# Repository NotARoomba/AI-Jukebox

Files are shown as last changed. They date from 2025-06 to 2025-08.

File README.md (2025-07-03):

<h1 align="center"> 
  <br>
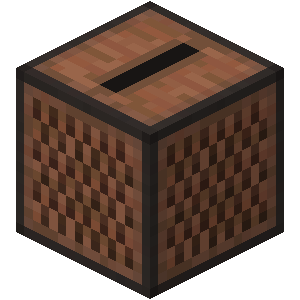
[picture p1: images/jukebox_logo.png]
Jukebox concept
  
  <br>
  AI Jukebox 
</h1>

<h4 align="center">A Minecraft‑inspired AI‑powered music jukebox using NFC‑tagged disks!

(Heavily) Inspired by [@danieliscrazy's jukebox](https://github.com/danieliscrazy/jukebox)

</h4>

<div align="center">





</div>

<p align="center">
  <a href="#key-features">Key Features</a> •
  <a href="#components-and-costs">Components & Costs</a> •
  <a href="#case-and-cad">Case & CAD</a> •
  <a href="3pcb-and-wiring">PCB & Wiring</a> •
  <a href="#credits">Credits</a>
</p>

## Key Features

- **NFC‑enabled Disks**: Insert‑to‑play AI‑generated tracks or playlists.
- **Satisfying Push‑Push Mechanics**: Disks can be entered and pushed out with a nice mechanism.
- **Custom Cube Frame**: 16 cm wooden case with 3D printed internals.
- **Audio Output**: Integrated speaker + MAX98357 amplifier, with Bluetooth support (via Raspberry PI).
- **Raspberry Pi Zero 2 W**: Powers logic and audio playback.
- **Playback Buttons**: Play/pause, fast forward/skip, or rewind/unskip music.

## Components & Costs

| Item | Price (COP) | Price (USD) | Source |
| --- | --- | --- | --- |
| Raspberry Pi Zero 2 W | 78,018 | 18.92 | [Aliexpress](https://es.aliexpress.com/item/1005007064834607.html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) |
| Speaker Amp Max98357  | 22,140 | 5.40 | [Online Marketplace](https://articulo.mercadolibre.com.co/MCO-2424374156-max98357-dac-convertidor-digital-analogico-amplificador-3w-_JM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) |
| Speaker | 23,024 | 5.67 | [Online Marketplace](https://www.mercadolibre.com.co/n-altavoz-tweeter-de-3-pulgadas-alta-fidelidad-4-ohmios/p/MCO2001722597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) |
| NFC Tags | 44,105 | 10.70 | [Online Marketplace](https://www.mercadolibre.com.co/a-100-unidadeslote-para-telefonos-con-chip-ntag215-nfc-pvc/p/MCO2011890227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) |
| RFID Kit RC522 | 12,500 | 3.03 | [Online Marketplace](https://articulo.mercadolibre.com.co/MCO-592398205-kit-rfid-rc522-receptor-tarjeta-y-llavero-_JM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) |
| Push Push Mechanism | 19,400 (already bought) | 4.71 | Local Hardware Store |
| 1cm Blocks of Wood | 33,760 (each, 2 units)  | 8.19 | [Temu](https://share.temu.com/08dAAkNGvvA) |
| Wood Glue | 19,900 | 4.83 | [Local Hardware Store](https://www.homecenter.com.co/homecenter-co/product/203373/pegante-carpincol-para-madera-250-gramos/203373/) |
| MX-Style Switches | 0 (already bought) | 0.00 | Already Purchased |
| DSA Keycaps | 0 (already bought) | 0.00 | Already Purchased |
| **SubTotal** | **307,650** | **74.68** | |
| **Shipping Costs** | **105,000** | **25.00** | Estimated |
| **Total** | **412,650** | **99.68** | |

## 📐 Case & CAD

- Designed in Fusion 360 as a 16 cm cube.
- 3D printed internal supports, wooden outer shell, and speaker cut‑out.
- Push‑push hardware custom‑fitted into disk slot.
- Buttons to play/pause, fastforward, and rewind

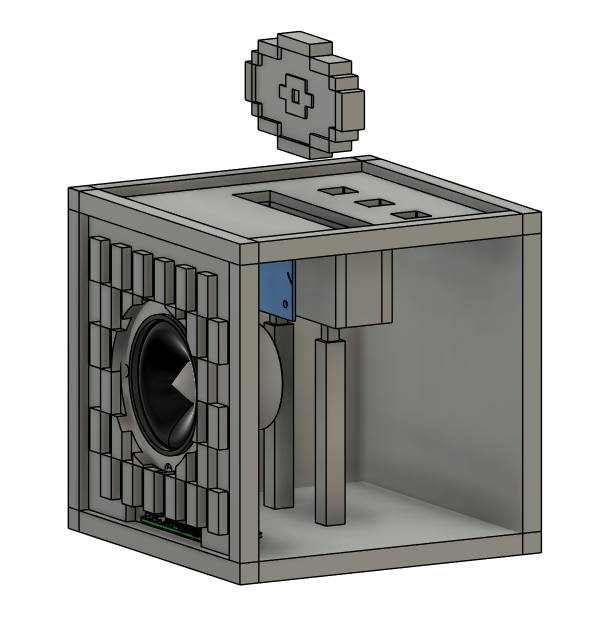
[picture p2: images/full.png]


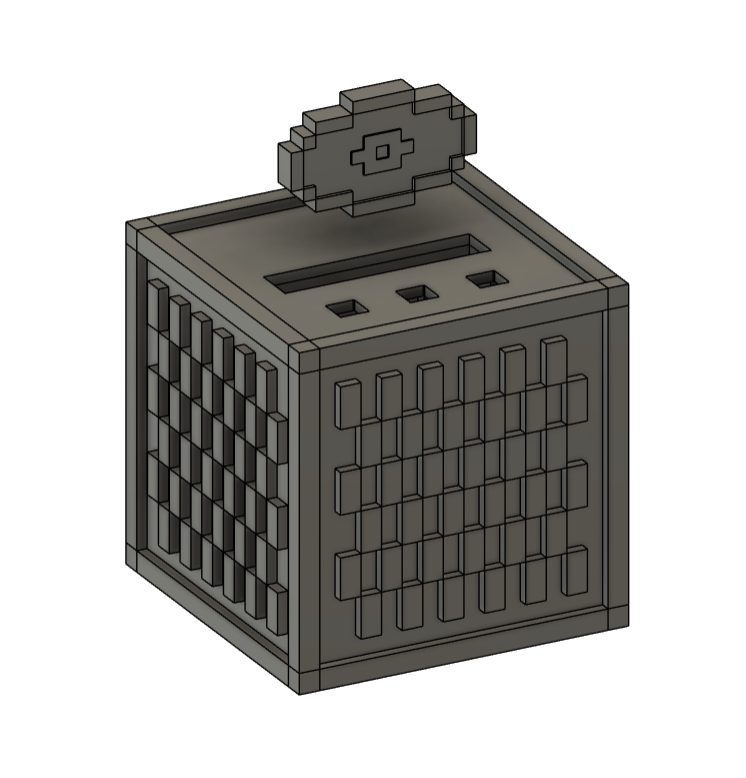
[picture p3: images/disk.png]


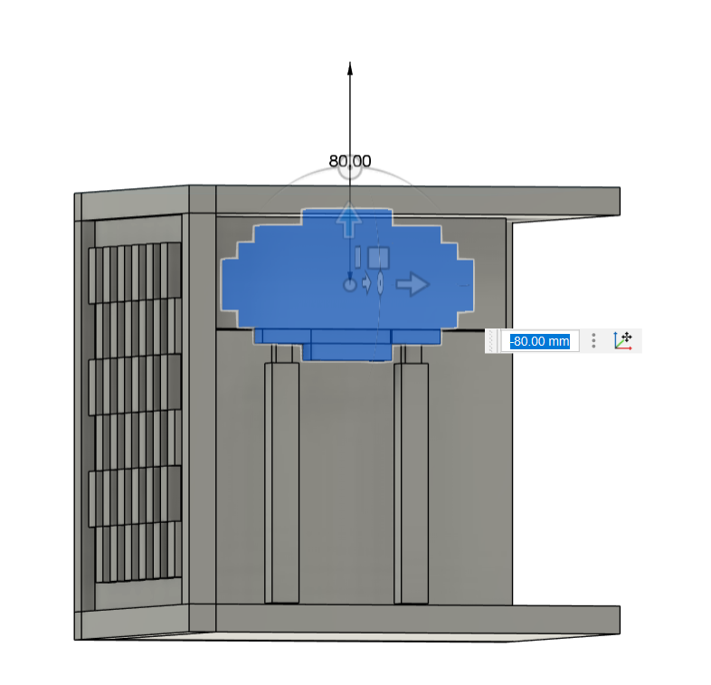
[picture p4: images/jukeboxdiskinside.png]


## PCB & Wiring

- Designed wiring in KiCad for Raspberry Pi ↔ RC522 NFC ↔ MAX98357 amp.
- Followed PiMyLifeUp tutorial for RC522, and Adafruit guide for MAX98357 wiring.
- MX-Style switches for play/pause and other functionality.

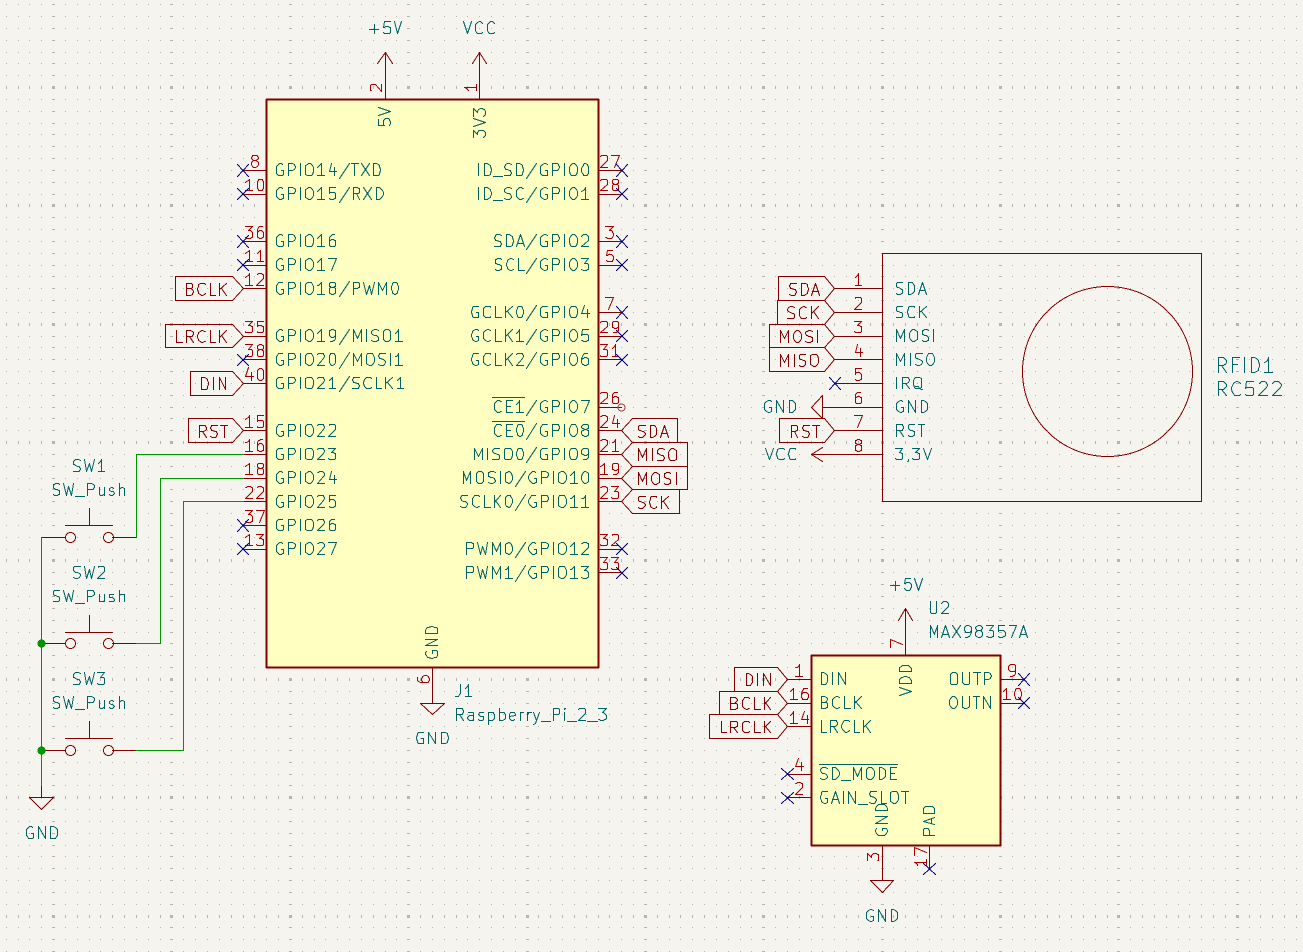
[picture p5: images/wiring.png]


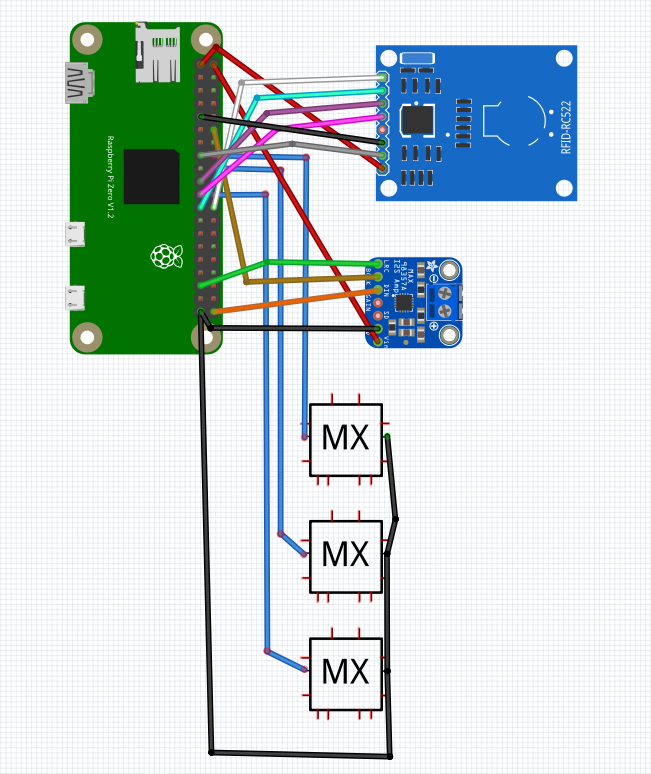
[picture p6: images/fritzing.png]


## Credits

Inspired by [@danieliscrazy's jukebox](https://github.com/danieliscrazy/jukebox)

This project uses:

- [KiCad](https://www.kicad.org/)
- [Python](https://www.python.org/)
- [Fusion 360](https://www.autodesk.com/products/fusion-360/overview)
- [RC522 Tutorial](https://pimylifeup.com/raspberry-pi-rfid-rc522/)
- [I2S Amp Guide](https://learn.adafruit.com/adafruit-max98357-i2s-class-d-mono-amp/raspberry-pi-wiring)

## You may also like...

- [Tamaki](https://github.com/NotARoomba/Tamaki) – Tamagotchi macropad
- [NivelesDeNiveles](https://github.com/NotARoomba/NivelesDeNiveles) – Flood alert app
- [ROCKETMEN](https://github.com/NotARoomba/ROCKETMEN) – Flight controller files

## License

MIT

> Disclaimer: Artificial intelligence was used in the making of this project's code and for some functionality. See `firmware/main.py` for more details.

---

> [notaroomba.dev](https://notaroomba.dev) &nbsp;&middot;&nbsp;
> GitHub [@NotARoomba](https://github.com/NotARoomba)

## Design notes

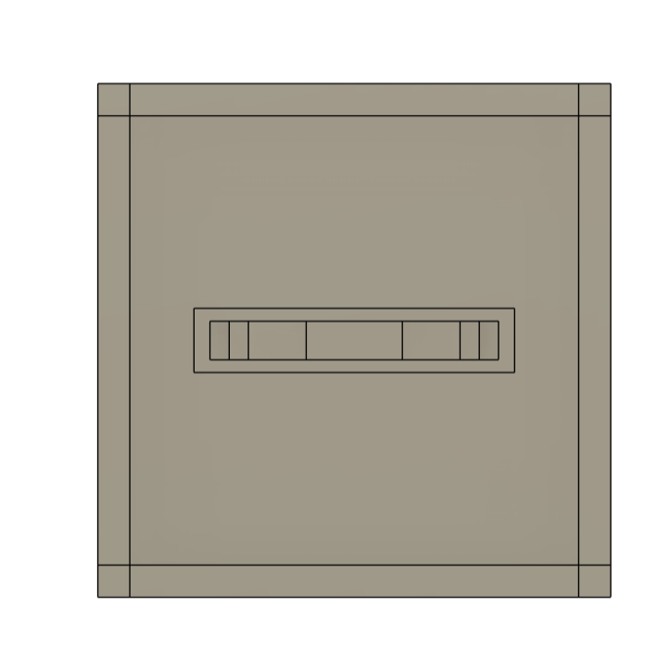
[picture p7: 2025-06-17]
images/disk_top.png

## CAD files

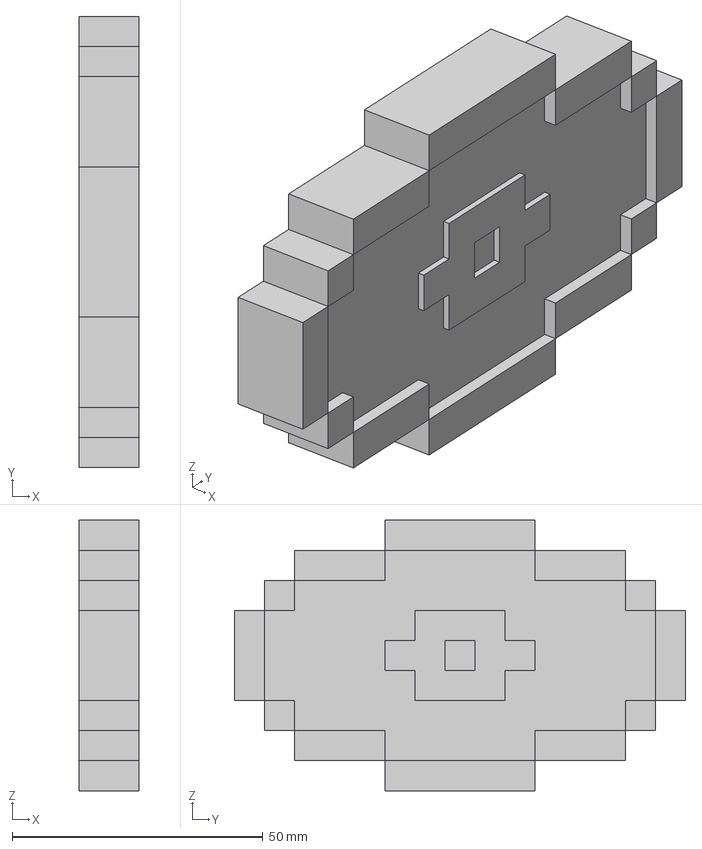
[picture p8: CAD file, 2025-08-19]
cad/Disk Hole.step
12.0 x 90.0 x 54.0 mm

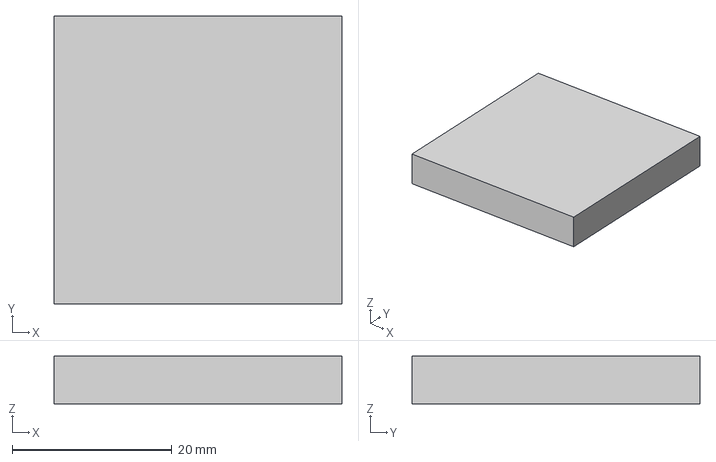
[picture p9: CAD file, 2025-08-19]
cad/Disk Test.step
36.0 x 36.0 x 6.00 mm

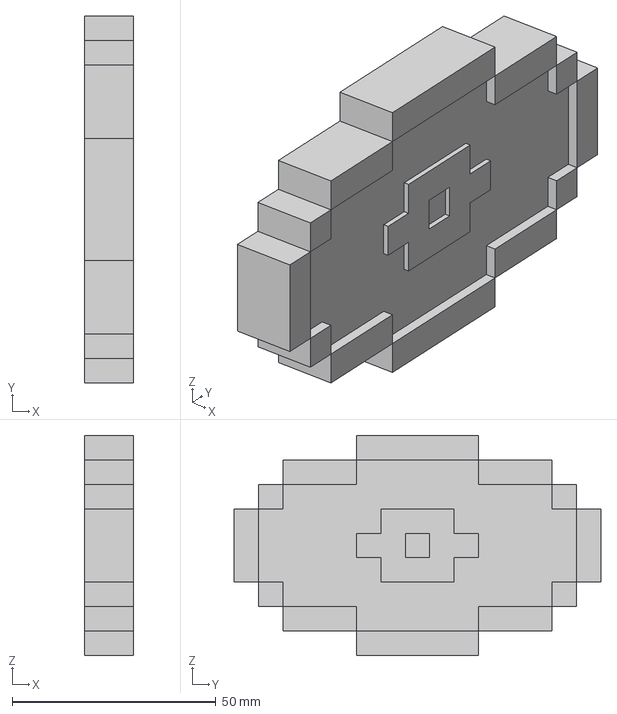
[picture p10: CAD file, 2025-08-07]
cad/Disk.step
12.0 x 90.0 x 54.0 mm

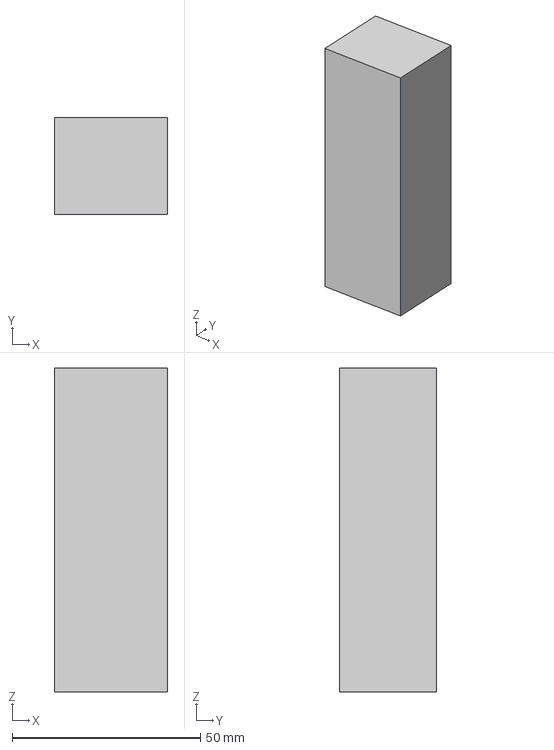
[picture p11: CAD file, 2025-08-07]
cad/Jukebox Support.step
30.0 x 25.7 x 86.0 mm

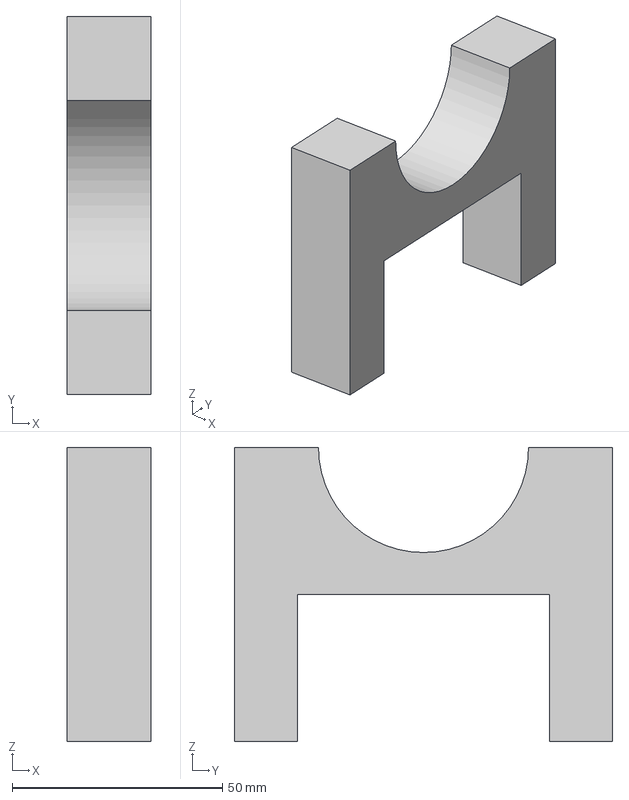
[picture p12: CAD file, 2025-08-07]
cad/Speaker Holder.step
20.0 x 90.0 x 70.0 mm

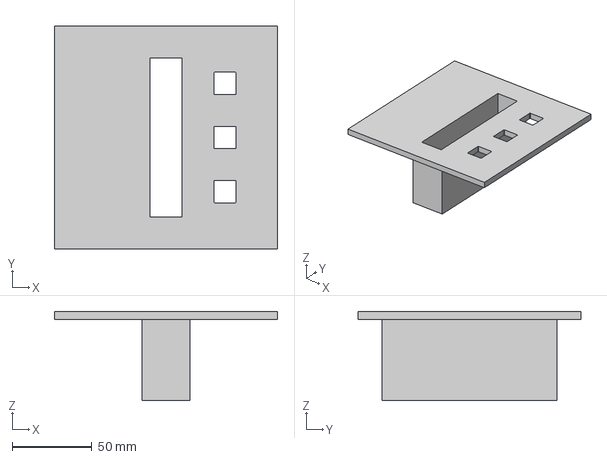
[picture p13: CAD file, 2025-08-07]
cad/Jukebox Top.step
140.0 x 140.0 x 56.0 mm

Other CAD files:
cad/Jukebox v21.f3z

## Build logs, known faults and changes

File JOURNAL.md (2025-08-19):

---
title: "AI Jukebox"
author: "Nathan Alspaugh (NotARoomba)"
description: "A Minecraft inspired jukebox that plays AI-generated music/albums from discs!"
created_at: "2025-06-13"
time_spent: ~23 Hours
---

# June 13: Brainstorming (~2 Hours)

I got inspired by the jukebox that was made and wanted to try and make my own with more features. One thing I had in mind was to have disks that have specific "prompts" encoded in the NFC tags to play music generated through Sumo from the prompt. Then I also wanted to have album-like disks where they play an album from spotify or something. Also a push-push mechanism for the disks as I think that feature would be satisfying to put in/take out the disks. I plan on making the frame from blocks of wood and then the insides with a combination of 3D printed parts. I would like to be able to place a speaker inside or for it to be able to connect to a speaker with aux/bluetooth.

# June 14: More Brainstorming and Case Design (~7 Hours)

I was looking into the different types of wood finishes as I wanted a jukebox that looked nice on the outside (the inside aswell) so I researched the wood types that I wanted to buy. For the border, I wanted an ebony or other dark wood, for the sides, I'm thinking about using a red mahogany/black walnut mix to create texture, and for the rest of the sides, maybe cherry wood.

I also worked on the case in Fusion360, it is going to be a cube thats 16x16x16cm.

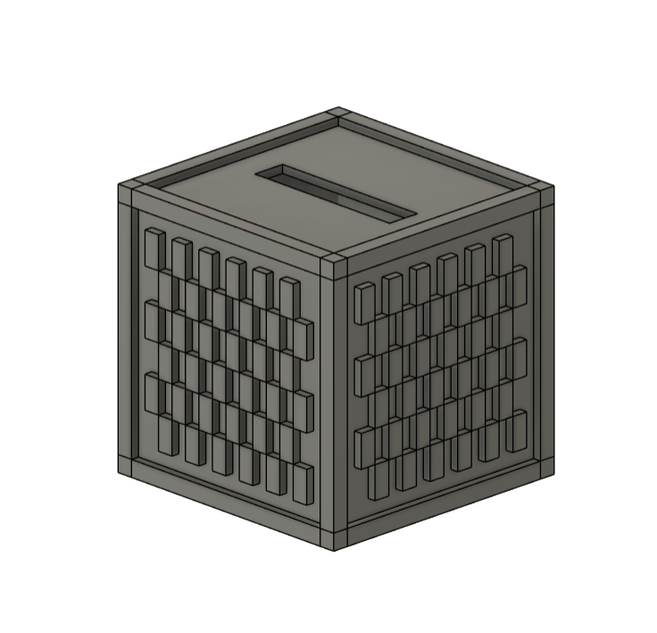
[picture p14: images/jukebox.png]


I also bought 2 "push push" cabinet mechanisms at my local hardware store to use for the disk. They are a bit strong so it will have enough force to literally "eject" the disk.



# June 15: Disc Design and Slot (~6 Hours)

I started design on the disk design and the slot in which the disks were going to be pushed into, keeping in mind the dimensions for the 2 push push mechanisms.

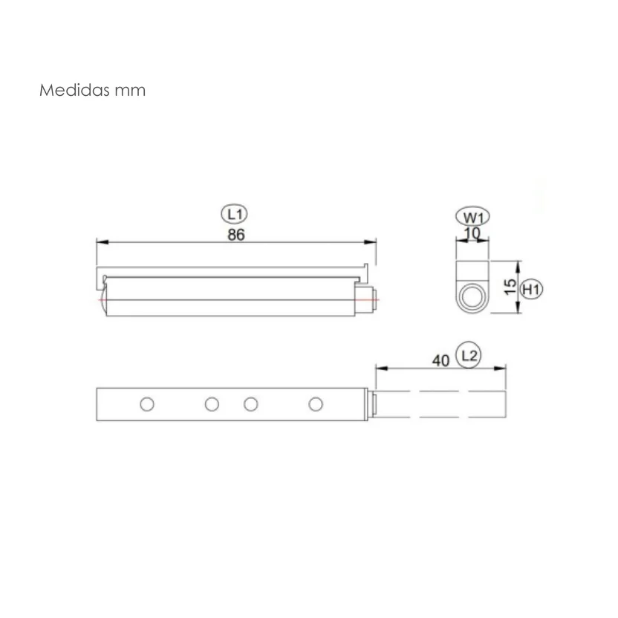
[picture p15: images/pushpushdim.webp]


I added in the 2 push mechanisms in to the bog to discover that they fit perfectly

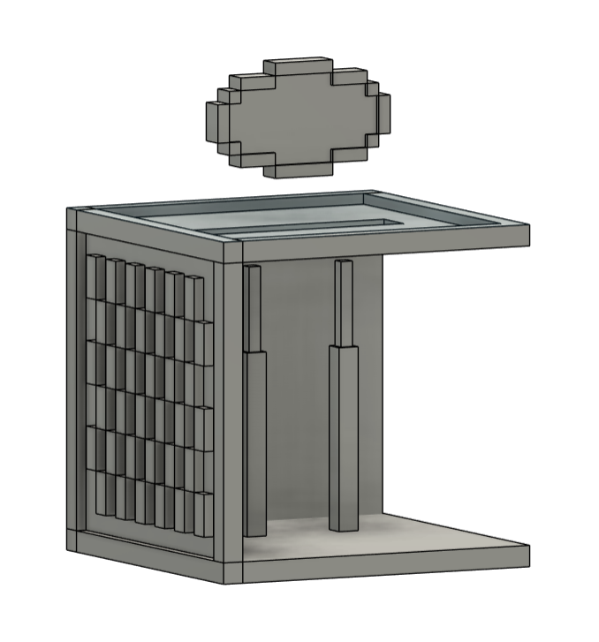
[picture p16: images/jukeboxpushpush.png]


Obviously there is going to be a "guide" for the disk so that it doesn't get jammed, I'll add the nfc tag reader to the side.



After that I added a hole for the speaker and the cables for the Raspberry Pi.

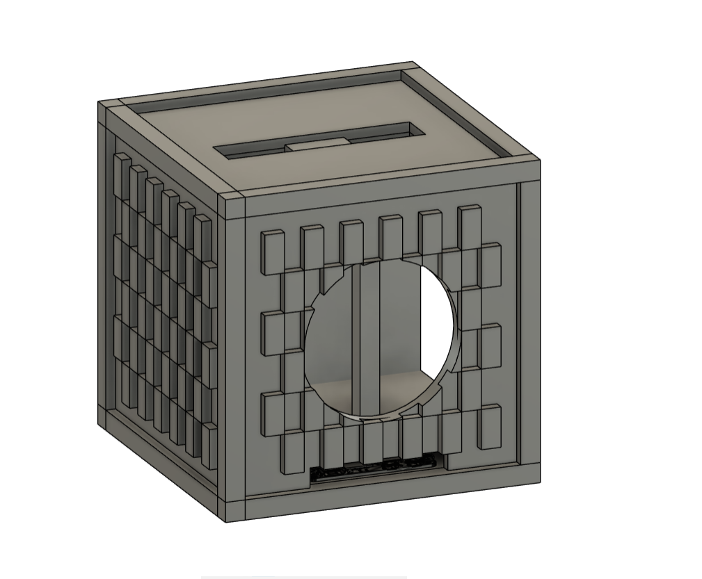
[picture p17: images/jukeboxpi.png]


# June 16: Connections (~6 Hours)

I went to the center of my city to try and find ebony but I had to leave because it is a semi dangerous place and I felt unsafe. I plan on returning with my mom to see if we can find it but for now I plan on ordering cubes on Temu and painting/staining them.

After making the box I fired up KiCad to connct the components, following a [tutorial](https://pimylifeup.com/raspberry-pi-rfid-rc522/) to connect the NFC reader to the Raspberry Pi and also a [guide by Adafruit](https://learn.adafruit.com/adafruit-max98357-i2s-class-d-mono-amp/raspberry-pi-wiring) for the amp wiring. The NFC is connected via SPI to the Raspberry PI and the amp is connected via a DAC. THe buttons I attached them to the GPIO inputs of the Raspberry PI.



# June 30: README Fixes and Code

I created some code and scripts that setup the nviroment based on the various guides for the NFC tag and Speaker. The code orks by assigning each disk a text and dpening on the text or the bitmask, it plays the correct minectaft disk or generates a song based on that bitmask.

# Future Work

When the cubes come in, I will have to paint each one and then cut, sand, and glue them together. After I plan on applying a finish to make the box look good. I think this will take a few days to up to a week.

# August 4:

After all of my parts finally came in I finished creating the wooden sides and decided to 3D print the top part as I had run out of wooden cubes.

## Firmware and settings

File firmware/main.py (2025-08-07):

#!/usr/bin/env python3

import os
import time
import re
import requests
import vlc
import RPi.GPIO as GPIO
from mfrc522 import MFRC522

BASE_URL = "http://localhost:3000"  # Suno API URL
VOLUME = 70

MOOD_FLAGS = {
    'HAPPY':       0x01,
    'SAD':         0x02,
    'ENERGETIC':   0x04,
    'CHILL':       0x08,
    'ROMANTIC':    0x10,
    'ANGRY':       0x20,
    'MELANCHOLIC': 0x40,
    'MYSTERIOUS':  0x80,
}

def extract_flags(mask: int) -> list:
    return [name for name, value in MOOD_FLAGS.items() if mask & value]

def generate_audio_by_prompt(payload):
    url = f"{BASE_URL}/api/generate"
    response = requests.post(url, json=payload, headers={'Content-Type': 'application/json'})
    return response.json()

def get_audio_information(audio_ids):
    url = f"{BASE_URL}/api/get?ids={audio_ids}"
    response = requests.get(url)
    return response.json()

def set_volume(volume_percent):
    try:
        import subprocess
        volume_percent = max(0, min(100, volume_percent))
        for mixer in ['Master', 'PCM', 'Speaker', 'Headphone']:
            try:
                result = subprocess.run(f"amixer set {mixer} {volume_percent}%", shell=True, capture_output=True, text=True)
                if result.returncode == 0:
                    print(f"Volume set to {volume_percent}% using {mixer} mixer")
                    return True
            except Exception:
                continue
        return False
    except Exception:
        return False

def get_volume():
    try:
        import subprocess
        for mixer in ['Master', 'PCM', 'Speaker', 'Headphone']:
            try:
                result = subprocess.run(f"amixer get {mixer}", shell=True, capture_output=True, text=True)
                if result.returncode == 0:
                    match = re.search(r'\[(\d+)%\]', result.stdout)
                    if match:
                        volume = int(match.group(1))
                        print(f"Current volume: {volume}% (using {mixer} mixer)")
                        return volume
            except Exception:
                continue
        return None
    except Exception:
        return None

def create_player(audio_url):
    print(f"Playing: {audio_url}")
    if audio_url.startswith('audio/') and not os.path.exists(audio_url):
        print(f"Audio file not found: {audio_url}")
        return None
    set_volume(VOLUME)
    player = vlc.MediaPlayer(audio_url)
    player.play()
    try:
        # Give VLC a moment to initialize, then set player volume to 0 for fade-in
        time.sleep(0.05)
        player.audio_set_volume(0)  # Start at 0 for fade-in
    except Exception:
        pass
    return player

def fade_in(player, fade_ms=800, steps=16):
    if player is None:
        return
    try:
        target = 100
        step = max(1, target // steps)
        delay = max(0.0, (fade_ms / 1000.0) / max(1, (target // step)))
        vol = 0
        while vol < target:
            player.audio_set_volume(vol)
            time.sleep(delay)
            vol += step
        player.audio_set_volume(target)
    except Exception:
        pass

def fade_out_and_stop(player, fade_ms=800, steps=16):
    if player is None:
        return
    try:
        current = player.audio_get_volume()
        if current is None or current < 0:
            current = 100
        step = max(1, current // steps)
        delay = max(0.0, (fade_ms / 1000.0) / max(1, (current // step)))
        vol = current
        while vol > 0:
            player.audio_set_volume(vol)
            time.sleep(delay)
            vol -= step
        player.audio_set_volume(0)
    except Exception:
        pass
    try:
        player.stop()
        player.release()
    except Exception:
        pass

def read_text_from_tag(reader):
    # Read NDEF Text record payload using same logic verified in test.py
    if not reader.IsNTAG():
        return None
    # Collect TLV data in 16-byte chunks (4 pages per read)
    data = bytearray()
    expected_total = None
    current_page = 4
    while current_page <= reader.NTAG_MaxPage:
        stat, block = reader.readNTAGBlock(current_page)
        if stat != reader.OK or not block:
            break
        data.extend(block)
        # Find TLV length when possible
        if expected_total is None and len(data) >= 2:
            tlv_idx = next((i for i,b in enumerate(data[:-1]) if b == 0x03), -1)
            if tlv_idx != -1 and len(data) >= tlv_idx + 2:
                tlv_len = data[tlv_idx + 1]
                header_extra = 0
                if tlv_len == 0xFF:
                    if len(data) >= tlv_idx + 4:
                        tlv_len = (data[tlv_idx + 2] << 8) | data[tlv_idx + 3]
                        header_extra = 2
                    else:
                        tlv_len = None
                if tlv_len is not None:
                    expected_total = tlv_idx + 2 + header_extra + tlv_len
        if expected_total is not None and len(data) >= expected_total:
            break
        current_page += 4

    if not data:
        return None

    # Parse TLV
    ndef_start = next((i for i,b in enumerate(data[:-1]) if b == 0x03), -1)
    if ndef_start == -1:
        return None
    ndef_length = data[ndef_start + 1]
    tlv_data_idx = ndef_start + 2
    if ndef_length == 0xFF:
        if len(data) < ndef_start + 4:
            return None
        ndef_length = (data[ndef_start + 2] << 8) | data[ndef_start + 3]
        tlv_data_idx = ndef_start + 4

    if tlv_data_idx + ndef_length > len(data):
        return None

    # Parse NDEF Short Text record: D1 01 <PL> 54 <status> 'en' <text>
    if ndef_length < 5:
        return None
    rec_header = data[tlv_data_idx]
    type_len = data[tlv_data_idx + 1]
    payload_len = data[tlv_data_idx + 2]
    if type_len != 1 or tlv_data_idx + 3 + type_len + payload_len > len(data):
        return None
    rec_type = data[tlv_data_idx + 3]
    if rec_type != 0x54:
        return None
    payload_idx = tlv_data_idx + 3 + type_len
    status = data[payload_idx]
    lang_len = status & 0x3F
    is_utf16 = (status & 0x80) != 0
    text_idx = payload_idx + 1 + lang_len
    text_len = payload_len - 1 - lang_len
    if text_len <= 0 or text_idx + text_len > len(data):
        return None
    try:
        return bytes(data[text_idx:text_idx+text_len]).decode('utf-16' if is_utf16 else 'utf-8')
    except Exception:
        return None

def process_text_payload(text):
    text = text.strip()
    if text.startswith('m_'):
        return 'minecraft', text[2:].strip()
    if text.startswith('a_'):
        try:
            return 'ai', int(text[2:].strip(), 16)
        except ValueError:
            return None, None
    return None, None

def main():
    GPIO.setwarnings(False)
    GPIO.setmode(GPIO.BCM)
    GPIO.cleanup()

    print("=== Volume Information ===")
    vol = get_volume()
    print(f"Default playback volume: {VOLUME}%")
    print("==========================")

    print("Initializing MFRC522...")
    reader = MFRC522(bus=0, device=0, spd=1000000, pin_mode=10, pin_rst=22)
    reader.DEBUG = False
    print("✓ MFRC522 ready")

    last_uid = None
    current_uid = None
    player = None
    playlist = []  # pending urls for AI two-part playback
    current_track_url = None
    last_tag_text = None
    presence_miss_count = 0
    try:
        print("Place an NFC card on the reader... Press Ctrl+C to exit")
        while True:
            # Poll for tag presence with debounce
            present_status, _ = reader.request(reader.REQIDL)
            if present_status != reader.OK:
                presence_miss_count += 1
                if current_uid is not None and presence_miss_count >= 5:
                    # Consider tag removed after consecutive misses
                    print("Tag removed. Fading out...")
                    if player is not None:
                        fade_out_and_stop(player)
                        player = None
                    playlist = []
                    current_track_url = None
                    current_uid = None
                    last_tag_text = None
                time.sleep(0.1)
                continue
            else:
                presence_miss_count = 0

            # Tag present, get UID
            status, uid = reader.SelectTagSN()
            if status != reader.OK:
                # Could be transient; do not treat as removal yet
                time.sleep(0.05)
                continue

            uid_str = ''.join([f'{b:02X}' for b in uid])

            # If new tag detected
            if uid_str != current_uid:
                current_uid = uid_str
                last_uid = uid_str
                print(f"Card UID: {uid_str}")

                # Read text FIRST to decide if we need to restart playback
                text = read_text_from_tag(reader)
                if not text:
                    print("No readable NDEF text on tag")
                    continue
                print(f"Tag text: {text}")

                song_type, song_data = process_text_payload(text)
                if song_type == 'minecraft':
                    audio_path = f"audio/{song_data}.mp3"
                    # If already playing this exact track, keep playing
                    if player is not None and current_track_url == audio_path and player.get_state() not in (vlc.State.Ended, vlc.State.Stopped, vlc.State.Error):
                        print("Already playing this track; continuing.")
                        last_tag_text = text
                    else:
                        # Stop existing playback only if changing track
                        if player is not None:
                            fade_out_and_stop(player)
                            player = None
                        playlist = []
                        current_track_url = None

                        print(f"Playing Minecraft: {song_data}")
                        player = create_player(audio_path)
                        current_track_url = audio_path if player else None
                        if player is not None:
                            fade_in(player)
                        last_tag_text = text
                elif song_type == 'ai':
                    mask = song_data
                    moods = extract_flags(mask)
                    # If the same AI spec text is already playing, skip
                    if player is not None and last_tag_text == text and player.get_state() not in (vlc.State.Ended, vlc.State.Stopped, vlc.State.Error):
                        print("Already playing this AI selection; continuing.")
                    else:
                        # Stop existing playback only if changing selection
                        if player is not None:
                            fade_out_and_stop(player)
                            player = None
                        playlist = []
                        current_track_url = None

                        print(f"Generating AI track with moods: {', '.join(moods)}")
                        data = generate_audio_by_prompt({
                            "prompt": f"Generate a song with the following moods: {', '.join(moods)}",
                            "make_instrumental": True,
                            "wait_audio": False
                        })
                        ids = f"{data[0]['id']},{data[1]['id']}"
                        # Wait until streaming, but abort if tag leaves or changes
                        ready_urls = None
                        for _ in range(60):
                            # Abort if tag removed or changed
                            st, _ = reader.request(reader.REQIDL)
                            if st != reader.OK:
                                print("Tag removed during AI generation; aborting.")
                                current_uid = None
                                break
                            s2, uid2 = reader.SelectTagSN()
                            if s2 != reader.OK or ''.join([f'{b:02X}' for b in uid2]) != uid_str:
                                print("Different tag detected during AI generation; aborting.")
                                break
                            info = get_audio_information(ids)
                            if info[0]["status"] == 'streaming':
                                ready_urls = [info[0]["audio_url"], info[1]["audio_url"]]
                                break
                            time.sleep(5)
                        if ready_urls:
                            playlist = ready_urls
                            # Start first
                            player = create_player(playlist[0])
                            current_track_url = playlist[0]
                            if player is not None:
                                fade_in(player)
                            # Keep remaining for later
                            playlist = playlist[1:]
                            last_tag_text = text
                else:
                    print("Unknown tag format. Expected 'm_<name>' or 'a_<hexFlags>'.")

            else:
                # Same tag still present; if track ended, advance playlist
                if player is not None:
                    state = player.get_state()
                    if state in (vlc.State.Ended, vlc.State.Stopped, vlc.State.Error):
                        try:
                            player.stop()
                            player.release()
                        except Exception:
                            pass
                        player = None
                        if playlist:
                            next_url = playlist.pop(0)
                            player = create_player(next_url)
                            current_track_url = next_url
                            if player is not None:
                                fade_in(player)

            time.sleep(0.1)
    except KeyboardInterrupt:
        pass
    finally:
        GPIO.cleanup()

if __name__ == '__main__':
    main()

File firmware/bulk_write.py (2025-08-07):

#!/usr/bin/env python3

import os
import sys
import time
import argparse
import RPi.GPIO as GPIO
from mfrc522 import MFRC522


def build_text_ndef_payload(text: str) -> bytes:
    # Build NDEF Text record (short record) wrapped in TLV 0x03 ... 0xFE
    lang = 'en'
    lang_bytes = lang.encode('ascii')
    text_bytes = text.encode('utf-8')
    status = len(lang_bytes) & 0x3F  # UTF-8
    payload_len = 1 + len(lang_bytes) + len(text_bytes)
    ndef = bytearray([0xD1, 0x01, payload_len, 0x54, status])
    ndef += lang_bytes
    ndef += text_bytes
    tlv = bytearray([0x03, len(ndef)])
    tlv += ndef
    tlv += b"\xFE"
    # pad to 4-byte boundary
    while len(tlv) % 4 != 0:
        tlv += b"\x00"
    return bytes(tlv)


def write_ndef_text(reader: MFRC522, text: str) -> bool:
    if not reader.IsNTAG():
        return False
    data = build_text_ndef_payload(text)
    page = 4
    idx = 0
    while idx < len(data) and page <= reader.NTAG_MaxPage:
        chunk = list(data[idx:idx+4])
        if len(chunk) < 4:
            chunk += [0] * (4 - len(chunk))
        if reader.writeNTAGPage(page, chunk) != reader.OK:
            return False
        idx += 4
        page += 1
        time.sleep(0.006)  # small settle time
    return True


def derive_tag_string_from_filename(filename: str) -> str:
    name, _ = os.path.splitext(filename)
    # If name starts with 'm_' treat as minecraft literal
    if name.startswith('m_'):
        return name
    # If AI file encodes hex flags after an underscore e.g. song_0F
    if '_' in name:
        maybe_flags = name.rsplit('_', 1)[-1]
        try:
            int(maybe_flags, 16)
            return f"a_{maybe_flags.upper()}"
        except ValueError:
            pass
    # Default to minecraft with the base name
    return f"m_{name}"


def main():
    parser = argparse.ArgumentParser(description='Bulk write NFC tags from audio files in a folder')
    parser.add_argument('-d', '--dir', default='audio', help='Folder containing audio files')
    parser.add_argument('--ext', default='.mp3', help='Audio file extension to scan')
    args = parser.parse_args()

    files = [f for f in sorted(os.listdir(args.dir)) if f.lower().endswith(args.ext.lower())]
    if not files:
        print(f"No {args.ext} files found in {args.dir}")
        return

    print("Initializing MFRC522...")
    reader = MFRC522(bus=0, device=0, spd=1000000, pin_mode=10, pin_rst=22)
    reader.DEBUG = False
    print("Ready. You'll be prompted to present a tag for each file.")

    try:
        for filename in files:
            tag_string = derive_tag_string_from_filename(filename)
            print("----------------------------------------")
            print(f"File: {filename}")
            print(f"Tag text to write: '{tag_string}'")
            input("Press Enter, then present tag to the reader...")

            # Wait for card
            while True:
                status, _ = reader.request(reader.REQIDL)
                if status == reader.OK:
                    status, uid = reader.SelectTagSN()
                    if status == reader.OK:
                        break
                time.sleep(0.05)

            if write_ndef_text(reader, tag_string):
                print("✓ Wrote tag successfully")
            else:
                print("✗ Failed to write tag")
            time.sleep(0.4)
    except KeyboardInterrupt:
        pass
    finally:
        GPIO.cleanup()


if __name__ == '__main__':
    main()

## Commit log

2025-06-20 added buttons
    [Jukbox.kicad_sch, Jukebox v10.step, Jukebox v13.step]
2025-06-30 added software and fixes
    [main.py]
